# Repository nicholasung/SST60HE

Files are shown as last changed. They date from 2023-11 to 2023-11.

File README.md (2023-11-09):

# SST60

## Changes
Added Hall effects under WASD for Gateron KS20
Removed the Hotswap diredctory as the solder is to keep consistent pcb and switch spacing

PCB is on rev 0.1 (theoretically ready but untested)

# Recommended Builds

### Budget $96 CAD Before PCB & Magnetics
  [Case $15](https://www.amazon.ca/Dciustfhe-Plastic-Mechanical-Keyboard-Shell/dp/B0BJPQZM5W/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), 
  [Switches $35](https://www.amazon.ca/Switch-Linear-Customization-Mechanical-Keyboard/dp/B0BQJ2Y3RX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), 
  [Plate $20](https://www.amazon.ca/stabilizers-Universal-Anodized-Aluminum-Positioning/dp/B06W2L4MCT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), 
  [Stabilizers $26](https://www.amazon.ca/DUROCK-Stabilizers-Translucent-Mechanical-Keyboard/dp/B08MWDGBJ8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), 
  This PCB, and 4x Gateron KS20s or Wooting Lekker Switches  

### Premium (My Personal Setup) ~$185 Before PCB & Magnetics
[Case, Plate, Stabs, $135](https://cannonkeys.com/products/bakeneko-60)
[Switches $35](https://www.aliexpress.com/item/1005004557654365.html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)

## Fully open source multi-layout 60% PCB
Render1
Render2
<sub> renders outdated, using the old outline. </sub>

## Layout support
KLE

## Features
- RGB Underglow
- RP2040 processor
- MX and Alps compatible
- Indicator light positions for Caps Lock and Esc
- Standard tray mount support
- Gummy O-Ring support (Bakenko, ogre, etc. anything that h60 supports, this does too.)
- USB-C or Unified Daughterboard (or equivalent with the same pinout)
- Overcurrent and ESD protection
- Flex meme cuts

## ***DISCLAIMER***
This PCB has been tested and confirmed to work properly. The members of the PCB development team are not liable if you end up with a non-functional pcb. Order at your own risk. Support will not be provided but pull requests will be reviewed and possibly accepted.

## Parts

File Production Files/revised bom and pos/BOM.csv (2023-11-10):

Comment | Designator | Footprint | JLCPCB Part #?optional?
1k | R_Crystal1,R_Flash1,R_RST1 | R_0402_1005Metric | C11702
PRTR5V0U2X | U4 | SOT143B | C12333
.1u | C_1V-Decoup2,C_1V-Decoup3,C_3V-Decoup3,C_3V-Decoup4,C_3V-Decoup5,C_3V-Decoup6,C_3V-Decoup7,C_3V-Decoup8,C_3V-Decoup9,C_Flash1 | C_0402_1005Metric | C1525
4.7n | C_Shield1 | C_0402_1005Metric | C1538
10u | C_3V-Decoup1 | C_0402_1005Metric | C15525
22pF | C_Crystal1,C_Crystal2 | C_0402_1005Metric | C1555
HRO-TYPE-C-31-M-12 | USB1 | HRO-TYPE-C-31-M-12-Assembly | C165948
RP2040 | U1 | RP2040-QFN-56 | C2040
27 | R_DATA1,R_DATA2 | R_0402_1005Metric | C25100
5k1 | R_USB1,R_USB2 | R_0402_1005Metric | C25905
1M | R_Shield1 | R_0402_1005Metric | C26083
Boot | SW1,SW2 | SW_SPST_TL3342 | C318884
1u | C_1V-Decoup1,C_3V-Decoup2,C_LDO1,C_LDO2 | C_0402_1005Metric | C52923
XC6206PxxxMR | U3 | SOT-23 | C5446
D_Small | D1,D10,D11,D12,D13,D14,D15,D16,D17,D18,D19,D2,D20,D21,D22,D23,D25,D26,D27,D28,D3,D30,D31,D32,D33,D34,D35,D36,D37,D38,D39,D4,D40,D41,D42,D43,D44,D45,D46,D48,D49,D5,D50,D51,D52,D53,D54,D55,D56,D57,D58,D59,D6,D61,D62,D63,D64,D65,D66,D67,D68,D7,D8,D9 | D_SOD-123 | C64898
74AHCT1G125 | U5 | SOT-23-5 | C7468
500mA | F1 | Fuse_0805_2012Metric | C883103
12MHz | Y1 | Crystal_SMD_3225-4Pin_3.2x2.5mm | C9002
W25Q128JVS | U2 | SOIC-8_5.23x5.23mm_P1.27mm | C97521
SM04B | J1 | JST_SH_SM04B-SRSS-TB_1x04-1MP_P1.00mm_Horizontal | C145956
Hall Sensor | W,A,S,D | SOT-23 | C2904393

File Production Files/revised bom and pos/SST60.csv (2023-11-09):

Id | Designator | Footprint | Quantity | Designation | Supplier and ref
1 | 1.25U,1.25U,1.25U,1.25U,1.25U,1.25U,1.25U,ISO | MX-1.25U-NoLED | 8 | MX-NoLED
2 | Small Split,N,2,2,T,[,R,S,H,D,J,Z,Split,W,-,V,X,1u,5,G,8,P,Q,Y,],1u/7u/10u,9,ISO,C,E,A,Split,0,L,I,M,F,1u,3,6,=,Split,K,2,7,O,4,U | MX-1U-NoLED | 48 | MX-NoLED
3 | REF** | SW_Cherry_MX_6.25u_PCB | 1 | SW_Cherry_MX_6.25u_PCB
4 | 1.50u,Tab,1.50u,1.50u,ANSI,1.50u | MX-1.5U-NoLED | 6 | MX-NoLED
5 | < | MX-1U-NoLED | 1 | ,
6 | Stepped | MX-1.25U-FLIPPED | 1 | MX-LED
7 | Split | MX-1.75U-NoLED | 1 | MX-NoLED
8 | : | MX-1U-NoLED | 1 | ;
9 | > | MX-1U-NoLED | 1 | .
10 | Full | MX-2.75U-NoLED | 1 | MX-NoLED
11 | ANSI,ANSI | MX-2.25U-NoLED | 2 | MX-NoLED
12 | Full | MX-2U-NoLED | 1 | MX-NoLED
13 | ? | MX-1U-NoLED | 1 | /
14 | ";MX-1U-NoLED" | 1 | '
15 | Esc | MX-1U | 1 | MX-LED
16 | Full | MX-1.75U | 1 | MX-LED
17 | U4 | SOT143B | 1 | PRTR5V0U2X
18 | SW2 | SW_SPST_TL3342 | 1 | Reset
19 | D19,D46,D15,D63,D35,D26,D54,D34,D50,D48,D22,D40,D14,D10,D61,D9,D37,D39,D2,D6,D1,D67,D13,D21,D52,D4,D3,D36,D12,D25,D30,D51,D28,D38,D45,D32,D55,D49,D5,D23,D20,D42,D64,D65,D16,D56,D27,D59,D58,D57,D43,D68,D66,D62,D18,D33,D8,D44,D53,D7,D31,D11,D41,D17 | D_SOD-123 | 64 | D_Small
20 | C_3V-Decoup8,C_1V-Decoup2,C_Flash1,C_3V-Decoup6,C_3V-Decoup7,C_3V-Decoup4,C_3V-Decoup5,C_3V-Decoup3,C_1V-Decoup3,C_3V-Decoup9 | C_0402_1005Metric | 10 | .1u
21 | D74,D71,D84,D78,D77,D72,D75,D76,D79,D70,D82,D81,D73,D83,D80,D69 | LED_WS2812_2020 | 16 | WS2812B-2020
22 | C_LDO2,C_3V-Decoup2,C_1V-Decoup1,C_LDO1 | C_0402_1005Metric | 4 | 1u
23 | A,W,S,D | SOT-23 | 4 | SOT-23
24 | C_Crystal2,C_Crystal1 | C_0402_1005Metric | 2 | 22pF
25 | R_Crystal1,R_RST1,R_Flash1 | R_0402_1005Metric | 3 | 1k
26 | R_LED1 | R_0402_1005Metric | 1 | 220
27 | USB1 | HRO-TYPE-C-31-M-12-Assembly | 1 | HRO-TYPE-C-31-M-12
28 | U1 | RP2040-QFN-56 | 1 | RP2040
29 | R_DATA2,R_DATA1 | R_0402_1005Metric | 2 | 27
30 | R_USB1,R_USB2 | R_0402_1005Metric | 2 | 5k1
31 | SW1 | SW_SPST_TL3342 | 1 | Boot
32 | R_Shield1 | R_0402_1005Metric | 1 | 1M
33 | Y1 | Crystal_SMD_3225-4Pin_3.2x2.5mm | 1 | 12MHz
34 | U5 | SOT-23-5 | 1 | 74AHCT1G125
35 | U3 | SOT-23 | 1 | XC6206PxxxMR
36 | C_Shield1 | C_0402_1005Metric | 1 | 4.7n
37 | U2 | SOIC-8_5.23x5.23mm_P1.27mm | 1 | W25Q128JVS
38 | F1 | Fuse_0805_2012Metric | 1 | 500mA
39 | C_3V-Decoup1 | C_0402_1005Metric | 1 | 10u

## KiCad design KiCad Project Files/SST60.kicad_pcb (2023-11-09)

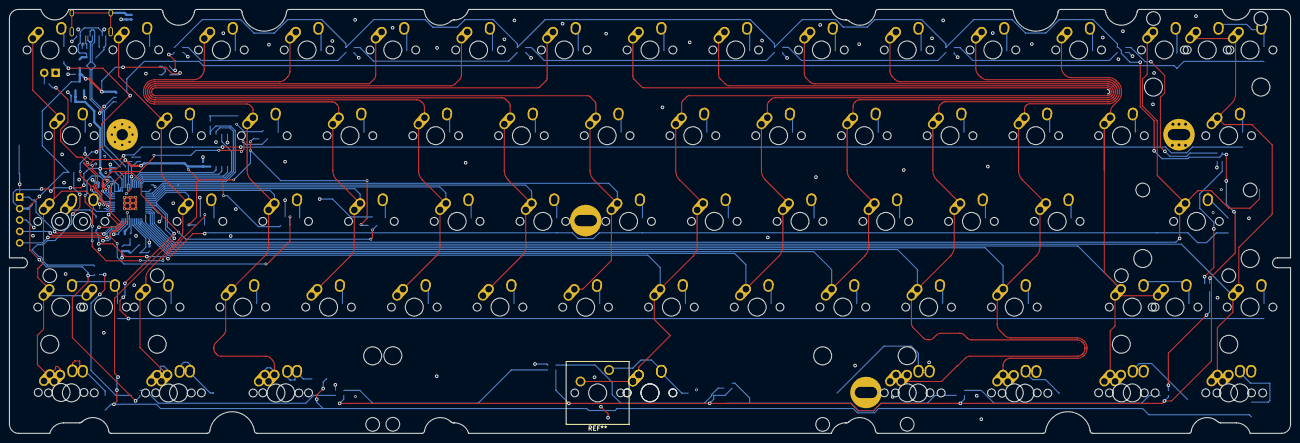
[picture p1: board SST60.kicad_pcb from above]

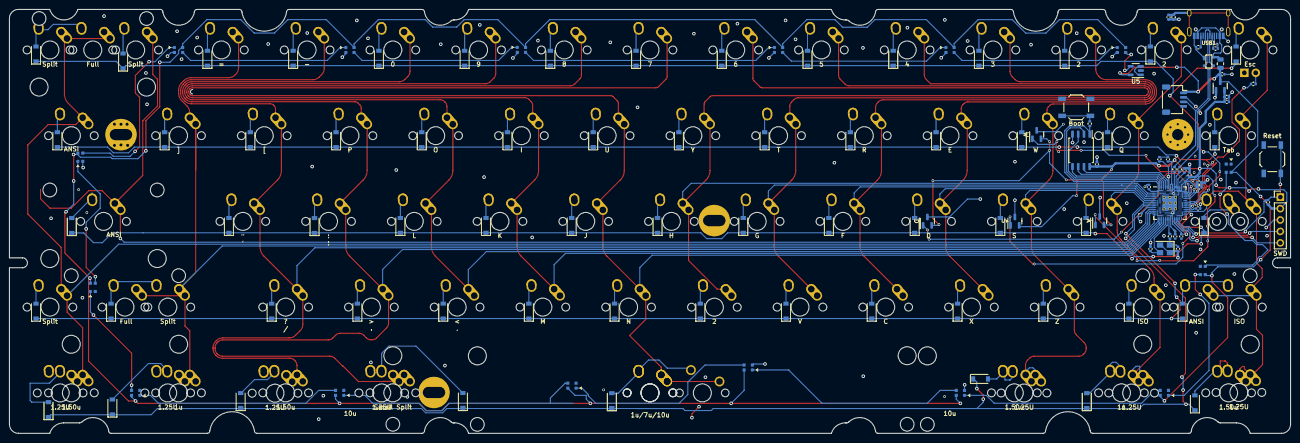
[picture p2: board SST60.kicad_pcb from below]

Board: 2 copper layers, 284.7 x 94.2 mm, 200 parts (123 on the bottom side), 132 nets.

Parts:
0, 1u, 1u#2, 1u/7u/10u, 2, 2#2, 2#3, 3, 4, 5, 6, 7, 8, 9: MX-NoLED; MX-1U-NoLED
1.25U, 1.25U#2, 1.25U#3, 1.25U#4, 1.25U#5, 1.25U#6, 1.25U#7: MX-NoLED; MX-1.25U-NoLED
1.50u, 1.50u#2, 1.50u#3, 1.50u#4: MX-NoLED; MX-1.5U-NoLED
": '; MX-1U-NoLED
-: MX-NoLED; MX-1U-NoLED
:: ;; MX-1U-NoLED
<: ,; MX-1U-NoLED
=: MX-NoLED; MX-1U-NoLED
>: .; MX-1U-NoLED
?: /; MX-1U-NoLED
A: MX-NoLED; MX-1U-NoLED
A#2: SOT-23
ANSI: MX-NoLED; MX-2.25U-NoLED
ANSI#2: MX-NoLED; MX-1.5U-NoLED
ANSI#3: MX-NoLED; MX-2.25U-NoLED
C: MX-NoLED; MX-1U-NoLED
C_1V-Decoup1, C_3V-Decoup2: 1u; C_0402_1005Metric
C_1V-Decoup2, C_1V-Decoup3, C_3V-Decoup3, C_3V-Decoup4, C_3V-Decoup5, C_3V-Decoup6, C_3V-Decoup7, C_3V-Decoup8, C_3V-Decoup9: .1u; C_0402_1005Metric
C_3V-Decoup1: 10u; C_0402_1005Metric
C_Crystal1, C_Crystal2: 22pF; C_0402_1005Metric
C_Flash1: .1u; C_0402_1005Metric
C_LDO1, C_LDO2: 1u; C_0402_1005Metric
C_Shield1: 4.7n; C_0402_1005Metric
D: MX-NoLED; MX-1U-NoLED
D1, D2, D3, D4, D5, D6, D7, D8, D9, D10, D11, D12, D13, D14, D15, D16, D17, D18, D19, D20, D21, D22, D23, D25, D26, D27, D28, D30, D31, D32, D33, D34, D35, D36, D37, D38, D39, D40, D41, D42, D43, D44, D45, D46, D48, D49, D50, D51, D52, D53, D54, D55, D56, D57, D58, D59, D61, D62, D63, D64, D65, D66, D67, D68: D_Small; D_SOD-123
D69, D70, D71, D72, D73, D74, D75, D76, D77, D78, D79, D80, D81, D82, D83, D84: WS2812B-2020; LED_WS2812_2020
D#2: SOT-23
E: MX-NoLED; MX-1U-NoLED
Esc: MX-LED; MX-1U
F: MX-NoLED; MX-1U-NoLED
F1: 500mA; Fuse_0805_2012Metric
Full: MX-NoLED; MX-2.75U-NoLED
Full#2: MX-NoLED; MX-2U-NoLED
Full#3: MX-LED; MX-1.75U
G: MX-NoLED; MX-1U-NoLED
H: MX-NoLED; MX-1U-NoLED
H1: PCB Outline; L60 Outline
I: MX-NoLED; MX-1U-NoLED
ISO: MX-NoLED; MX-1U-NoLED
ISO#2: MX-NoLED; MX-1.25U-NoLED
J: MX-NoLED; MX-1U-NoLED
J1: SM04B; JST_SH_SM04B-SRSS-TB_1x04-1MP_P1.00mm_Horizontal
J2: SWD; PinHeader_1x05_P2.54mm_Vertical
K: MX-NoLED; MX-1U-NoLED
L: MX-NoLED; MX-1U-NoLED
M: MX-NoLED; MX-1U-NoLED
MX42: MX-NoLED; MX-7U-ReversedStabilizers-NoLED
N: MX-NoLED; MX-1U-NoLED
O: MX-NoLED; MX-1U-NoLED
P: MX-NoLED; MX-1U-NoLED
Q: MX-NoLED; MX-1U-NoLED
R: MX-NoLED; MX-1U-NoLED
R_Crystal1: 1k; R_0402_1005Metric
R_DATA1, R_DATA2: 27; R_0402_1005Metric
R_Flash1: 1k; R_0402_1005Metric
R_LED1: 220; R_0402_1005Metric
R_RST1: 1k; R_0402_1005Metric
R_Shield1: 1M; R_0402_1005Metric
R_USB1, R_USB2: 5k1; R_0402_1005Metric
S: MX-NoLED; MX-1U-NoLED
S#2: SOT-23
SW1: Boot; SW_SPST_TL3342
SW2: Reset; SW_SPST_TL3342
Small Split: MX-NoLED; MX-1U-NoLED
Split: MX-NoLED; MX-1U-NoLED
Split#2: MX-NoLED; MX-1.75U-NoLED
Split#3, Split#4: MX-NoLED; MX-1U-NoLED
Stepped: MX-LED; MX-1.25U-FLIPPED
T: MX-NoLED; MX-1U-NoLED
Tab: MX-NoLED; MX-1.5U-NoLED
U: MX-NoLED; MX-1U-NoLED
U1: RP2040; RP2040-QFN-56
U2: W25Q128JVS; SOIC-8_5.23x5.23mm_P1.27mm
U3: XC6206PxxxMR; SOT-23
U4: PRTR5V0U2X; SOT143B
U5: 74AHCT1G125; SOT-23-5
USB1: HRO-TYPE-C-31-M-12; HRO-TYPE-C-31-M-12-Assembly
V: MX-NoLED; MX-1U-NoLED
W: MX-NoLED; MX-1U-NoLED
W#2: SOT-23
X: MX-NoLED; MX-1U-NoLED
Y: MX-NoLED; MX-1U-NoLED
Y1: 12MHz; Crystal_SMD_3225-4Pin_3.2x2.5mm
Z: MX-NoLED; MX-1U-NoLED
[: MX-NoLED; MX-1U-NoLED
]: MX-NoLED; MX-1U-NoLED

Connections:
+1V1: C_1V-Decoup1.1, C_1V-Decoup2.1, C_1V-Decoup3.1, U1.23 (DVDD), U1.45 (VREG_VOUT), U1.50 (DVDD)
+3V3: A#2.VDD, C_3V-Decoup1.1, C_3V-Decoup2.1, C_3V-Decoup3.1, C_3V-Decoup4.1, C_3V-Decoup5.1, C_3V-Decoup6.1, C_3V-Decoup7.1, C_3V-Decoup8.1, C_3V-Decoup9.1, C_Flash1.1, C_LDO2.1, D#2.VDD, J2.2, R_RST1.1, S#2.VDD, U1.1 (IOVDD), U1.10 (IOVDD), U1.22 (IOVDD), U1.33 (IOVDD), U1.42 (IOVDD), U1.43 (ADC_AVDD), U1.44 (VREG_VIN), U1.48 (USB_VDD), U1.49 (IOVDD), U2.8 (VCC), U3.2 (VO), W#2.VDD
+5V: C_LDO1.1, D69.4 (VDD), D70.4 (VDD), D71.4 (VDD), D72.4 (VDD), D73.4 (VDD), D74.4 (VDD), D75.4 (VDD), D76.4 (VDD), D77.4 (VDD), D78.4 (VDD), D79.4 (VDD), D80.4 (VDD), D81.4 (VDD), D82.4 (VDD), D83.4 (VDD), D84.4 (VDD), F1.2, J1.1, U3.3 (VI), U5.5 (+5V)
A: A#2.A, U1.39 (GPIO27/ADC1)
CS: R_Flash1.2, U1.56 (QSPI_SS_N), U2.1 (~CS)
D: D#2.D, U1.41 (GPIO29/ADC3)
D+: J1.3, R_DATA1.1, U4.2 (IO1), USB1.6 (DP1), USB1.8 (DP2)
D-: J1.2, R_DATA2.1, U4.3 (IO2), USB1.5 (DN2), USB1.7 (DN1)
ESCLED: R_LED1.1, U1.34 (GPIO22)
GND: A#2.GND, C_1V-Decoup1.2, C_1V-Decoup2.2, C_1V-Decoup3.2, C_3V-Decoup1.2, C_3V-Decoup2.2, C_3V-Decoup3.2, C_3V-Decoup4.2, C_3V-Decoup5.2, C_3V-Decoup6.2, C_3V-Decoup7.2, C_3V-Decoup8.2, C_3V-Decoup9.2, C_Crystal1.1, C_Crystal2.1, C_Flash1.2, C_LDO1.2, C_LDO2.2, C_Shield1.1, D69.2 (VSS), D70.2 (VSS), D71.2 (VSS), D72.2 (VSS), D73.2 (VSS), D74.2 (VSS), D75.2 (VSS), D76.2 (VSS), D77.2 (VSS), D78.2 (VSS), D79.2 (VSS), D80.2 (VSS), D81.2 (VSS), D82.2 (VSS), D83.2 (VSS), D84.2 (VSS), D#2.GND, Esc.4 (LEDGND), H1.1, J1.4, J2.3, R_Shield1.2, R_USB1.2, R_USB2.2, S#2.GND, SW1.1, SW2.2, U1.19 (TESTEN), U1.57 (GND), U2.4 (GND), U3.1 (GND), U4.1 (GND), U5.1, U5.3 (GND), USB1.1 (GND), USB1.12 (GND), W#2.GND, Y1.2, Y1.4
GNDREF: C_Shield1.2, R_Shield1.1, USB1.13 (SHIELD)
unnamed: C_Crystal2.2, R_Crystal1.1, Y1.1
unnamed: D1.2 (A), Esc.2 (ROW)
unnamed: D2.2 (A), Tab.2 (ROW)
unnamed: D3.2 (A), Full#3.1 (ROW), Stepped.2 (ROW)
unnamed: ANSI#3.2 (ROW), D4.2 (A), ISO#2.2 (ROW)
unnamed: 1.25U#6.2 (ROW), 1.50u.2 (ROW), D5.2 (A)
unnamed: 2.2 (ROW), D6.2 (A)
unnamed: D7.2 (A), Q.2 (ROW)
unnamed: A.2 (ROW), D8.2 (A)
unnamed: D9.2 (A), ISO.2 (ROW)
unnamed: 1.25U.2 (ROW), 1u#2.2 (ROW), D10.2 (A)
unnamed: D11.2 (A), Z.2 (ROW)
unnamed: 2#3.2 (ROW), D12.2 (A)
unnamed: D13.2 (A), W.2 (ROW)
unnamed: D14.2 (A), S.2 (ROW)
unnamed: 1.25U#2.2 (ROW), 1.50u#3.2 (ROW), D15.2 (A)
unnamed: 3.2 (ROW), D16.2 (A)
unnamed: D17.2 (A), E.2 (ROW)
unnamed: D.2 (ROW), D18.2 (A)
unnamed: D19.2 (A), X.2 (ROW)
unnamed: 4.2 (ROW), D20.2 (A)
unnamed: D21.2 (A), R.2 (ROW)
unnamed: D22.2 (A), F.2 (ROW)
unnamed: C.2 (ROW), D23.2 (A)
unnamed: 5.2 (ROW), D25.2 (A)
unnamed: D26.2 (A), T.2 (ROW)
unnamed: D27.2 (A), G.2 (ROW)
unnamed: D28.2 (A), V.2 (ROW)
unnamed: 6.2 (ROW), D30.2 (A)
unnamed: D31.2 (A), Y.2 (ROW)
unnamed: D32.2 (A), H.2 (ROW)
unnamed: 2#2.2 (ROW), D33.2 (A)
unnamed: 7.2 (ROW), D34.2 (A)
unnamed: D35.2 (A), U.2 (ROW)
unnamed: D36.2 (A), J.2 (ROW)
unnamed: D37.2 (A), N.2 (ROW)
unnamed: 1u/7u/10u.2 (ROW), D38.2 (A), MX42.2 (ROW)
unnamed: 8.2 (ROW), D39.2 (A)
unnamed: D40.2 (A), I.2 (ROW)
unnamed: D41.2 (A), K.2 (ROW)
unnamed: D42.2 (A), M.2 (ROW)
unnamed: 9.2 (ROW), D43.2 (A)
unnamed: D44.2 (A), O.2 (ROW)
unnamed: D45.2 (A), L.2 (ROW)
unnamed: <.2 (ROW), D46.2 (A)
unnamed: 0.2 (ROW), D48.2 (A)
unnamed: D49.2 (A), P.2 (ROW)
unnamed: :.2 (ROW), D50.2 (A)
unnamed: >.2 (ROW), D51.2 (A)
unnamed: 1.25U#3.2 (ROW), 1.25U#3.d52 (ROW), D52.2 (A), Small Split.2 (ROW)
unnamed: -.2 (ROW), D53.2 (A)
unnamed: D54.2 (A), [.2 (ROW)
unnamed: ".2 (ROW), D55.2 (A)
unnamed: ?.2 (ROW), D56.2 (A)
unnamed: 1.25U#7.2 (ROW), 1.50u#2.2 (ROW), D57.2 (A)
unnamed: =.2 (ROW), D58.2 (A)
unnamed: D59.2 (A), ].2 (ROW)
unnamed: D61.2 (A), Full.2 (ROW), Split#2.2 (ROW)
unnamed: 1.25U#5.2 (ROW), 1u.2 (ROW), D62.2 (A)
unnamed: D63.2 (A), Split#4.2 (ROW)
unnamed: ANSI.2 (ROW), D64.2 (A)
unnamed: D65.2 (A), Full#2.2 (ROW), Split#3.2 (ROW)
unnamed: ANSI#2.2 (ROW), D66.2 (A)
unnamed: D67.2 (A), Split.2 (ROW)
unnamed: 1.25U#4.2 (ROW), 1.50u#4.2 (ROW), D68.2 (A)
unnamed: D69.3 (DIN), D70.1 (DOUT)
unnamed: D70.3 (DIN), D72.1 (DOUT)
unnamed: D71.1 (DOUT), D73.3 (DIN)
unnamed: D72.3 (DIN), D74.1 (DOUT)
unnamed: D73.1 (DOUT), D75.3 (DIN)
unnamed: D74.3 (DIN), D76.1 (DOUT)
unnamed: D75.1 (DOUT), D77.3 (DIN)
unnamed: D76.3 (DIN), D78.1 (DOUT)
unnamed: D77.1 (DOUT), D79.3 (DIN)
unnamed: D78.3 (DIN), D80.1 (DOUT)
unnamed: D79.1 (DOUT), D81.3 (DIN)
unnamed: D80.3 (DIN), D82.1 (DOUT)
unnamed: D81.1 (DOUT), D83.3 (DIN)
unnamed: D82.3 (DIN), D84.1 (DOUT)
unnamed: D83.1 (DOUT), D84.3 (DIN)
unnamed: Esc.3 (LED), R_LED1.2
unnamed: R_DATA1.2, U1.47 (D+)
unnamed: R_DATA2.2, U1.46 (D-)
unnamed: R_Flash1.1, SW1.2
unnamed: R_USB1.1, USB1.4 (CC1)
unnamed: R_USB2.1, USB1.10 (CC2)
QSPI_CLK: U1.52 (QSPI_SCLK), U2.6 (CLK)
RESET: J2.1, R_RST1.2, SW2.1, U1.26 (~RUN)
RGB: D71.3 (DIN), U5.4
RGBLED: U1.37 (GPIO25), U5.2
S: S#2.S, U1.40 (GPIO28/ADC2)
SD0: U1.53 (QSPI_SD0), U2.5 (DI(IO0))
SD1: U1.55 (QSPI_SD1), U2.2 (DO(IO1))
SD2: U1.54 (QSPI_SD2), U2.3 (IO2)
SD3: U1.51 (QSPI_SD3), U2.7 (IO3)
SWCLK: J2.5, U1.24 (SWCLK)
SWDIO: J2.4, U1.25 (SWDIO)
VCC: F1.1, U4.4 (VCC), USB1.2 (VBUS), USB1.11 (VBUS)
W: U1.38 (GPIO26/ADC0), W#2.W
XTAL_IN: C_Crystal1.2, U1.20 (XTAL_IN), Y1.3
XTAL_OUT: R_Crystal1.2, U1.21 (XTAL_OUT)
col0: 1.25U#6.1 (COL), 1.50u.1 (COL), ANSI#3.1 (COL), Esc.1 (COL), Full#3.2 (COL), ISO#2.1 (COL), Stepped.1 (COL), Tab.1 (COL), U1.32 (GPIO21)
col1: 1.25U.1 (COL), 1u#2.1 (COL), 2.1 (COL), A.1 (COL), ISO.1 (COL), Q.1 (COL), U1.7 (GPIO5)
col2: 1.25U#2.1 (COL), 1.50u#3.1 (COL), 2#3.1 (COL), S.1 (COL), U1.6 (GPIO4), W.1 (COL), Z.1 (COL)
col3: 3.1 (COL), D.1 (COL), E.1 (COL), U1.5 (GPIO3), X.1 (COL)
col4: 4.1 (COL), C.1 (COL), F.1 (COL), R.1 (COL), U1.4 (GPIO2)
col5: 5.1 (COL), G.1 (COL), T.1 (COL), U1.3 (GPIO1), V.1 (COL)
col6: 2#2.1 (COL), 6.1 (COL), H.1 (COL), U1.2 (GPIO0), Y.1 (COL)
col7: 1u/7u/10u.1 (COL), 7.1 (COL), J.1 (COL), MX42.1 (COL), N.1 (COL), U.1 (COL), U1.18 (GPIO15)
col8: 8.1 (COL), I.1 (COL), K.1 (COL), M.1 (COL), U1.17 (GPIO14)
col9: 9.1 (COL), <.1 (COL), L.1 (COL), O.1 (COL), U1.16 (GPIO13)
col10: 0.1 (COL), 1.25U#3.1 (COL), :.1 (COL), >.1 (COL), P.1 (COL), Small Split.1 (COL), U1.15 (GPIO12)
col11: 1.25U#7.1 (COL), 1.50u#2.1 (COL), ".1 (COL), -.1 (COL), ?.1 (COL), U1.14 (GPIO11), [.1 (COL)
col12: 1.25U#5.1 (COL), 1u.1 (COL), =.1 (COL), Full.1 (COL), Split#2.1 (COL), U1.13 (GPIO10), ].1 (COL)
col13: ANSI.1 (COL), Split#4.1 (COL), U1.11 (GPIO8)
col14: 1.25U#4.1 (COL), 1.50u#4.1 (COL), ANSI#2.1 (COL), Full#2.1 (COL), Split.1 (COL), Split#3.1 (COL), U1.12 (GPIO9)
row0: D1.1 (K), D6.1 (K), D12.1 (K), D16.1 (K), D20.1 (K), D25.1 (K), D30.1 (K), D34.1 (K), D39.1 (K), D43.1 (K), D48.1 (K), D53.1 (K), D58.1 (K), D63.1 (K), D65.1 (K), U1.36 (GPIO24)
row1: D2.1 (K), D7.1 (K), D13.1 (K), D17.1 (K), D21.1 (K), D26.1 (K), D31.1 (K), D35.1 (K), D40.1 (K), D44.1 (K), D49.1 (K), D54.1 (K), D59.1 (K), D66.1 (K), U1.35 (GPIO23)
row2: D3.1 (K), D8.1 (K), D14.1 (K), D18.1 (K), D22.1 (K), D27.1 (K), D32.1 (K), D36.1 (K), D41.1 (K), D45.1 (K), D50.1 (K), D55.1 (K), D64.1 (K), U1.31 (GPIO20)
row3: D4.1 (K), D9.1 (K), D11.1 (K), D19.1 (K), D23.1 (K), D28.1 (K), D33.1 (K), D37.1 (K), D42.1 (K), D46.1 (K), D51.1 (K), D56.1 (K), D61.1 (K), D67.1 (K), U1.8 (GPIO6)
row4: D5.1 (K), D10.1 (K), D15.1 (K), D38.1 (K), D52.1 (K), D57.1 (K), D62.1 (K), D68.1 (K), U1.9 (GPIO7)

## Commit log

2023-11-08 Add files via upload
    updated schematics
    [MCU.kicad_sch, Misc.kicad_sch, SST60.kicad_sch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]
2023-11-09 Wired up the hall effects, removed some led traces and the flex cuts
2023-11-09 Added FR4 Plate files
    Based on GH60 and Bakeneko plates
    [bakeneko-60-fr4-plate.kicad_pcb, bakeneko-60-fr4-plate.sch, universal-60.kicad_pcb]
2023-11-09 Reworked Bottom Row
    Now only supports ansi and tsangan sacrificing flexibility for simplicity and wider standards.
    [MCU.kicad_sch, Misc.kicad_sch, SST60.kicad_pcb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]
2023-11-09 Cleaned Traces
    Updated traces, generated new gerber, pos and bom, removed iso enter support
    [SST60-B_Cu.gbl, SST60-B_Mask.gbs, SST60-B_Paste.gbp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]
2023-11-09 fixed missing trace
    [SST60.kicad_pcb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]
2023-11-09 added traces for "c" and "1"
    [SST60.kicad_pcb]
2023-11-10 BOM and POS files added
    Both JST and USB are installed on default.
    [BOM.csv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]
2023-11-10 cleaned up dirs
    [MCU.kicad_sch, Misc.kicad_sch, SST60.kicad_pcb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]
2023-11-10 BOM and POS are fully matching pcb
    [BOM.csv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]
